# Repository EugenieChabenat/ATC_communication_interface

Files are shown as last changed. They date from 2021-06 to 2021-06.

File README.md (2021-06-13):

# Assistive Technology Challenge: Team Communication
## HackaHealth Geneva 

## Context 
A device  has been developed by this team, to serve as a communication interface for an 8-year-old child that cannot speak but is eager to interact with his environment. 
He needs an efficient tool to communicate and control his tablet (that runs the Grid3 software). 
The goal is to give him more autonomy and a more accurate communication system. 
Our challenges are first of all to create a device easy to use for a child and that does not increase his fatigue. 
We have to consider the low precision of the movements as well as a not very well controlled head hold. 
Our device must meet the criteria of safety, biocompatibility and be easy to use for both the family and the therapists. 
In addition, we aim to produce an object that is easily reproducible, open source and within a reasonable budget. 
This repository contains the codes used for this device, as well as some files for reproducibility of the device itself. 

## File description 
**CAD_files**

- readme_CAD_files

CAD_files/DXF_laser_cutting/ : *CAD files that can be used for laser cutting the pieces of the device*

- readme_DXF_laser_cutting.txt
- cover_window_PMMA_3mm.dxf
- frame_window_PMMA_8mm.dxf
- support_1_CP_aviation_1mm.dxf
- support_2_MDF_4mm.dxf
- support_3_MDF_4mm.dxf

CAD_files/F3D_files/ : *Fusion files of the different pieces for 3d printing*

- readme_F3D_files.txt
- Support_1.f3d
- Support_2.f3d
- Support_3.f3d
- closing_electronic_box.f3d
- cover_window.f3d
- electronic_boc.f3d
- fixation.f3d
- safety_ring.f3d
- tube_cap.f3d
- window_frame_final v4.f3d

CAD_files/STEP_files/ : *Files for 3D printing*

- readme_STEP_files
- Support_1.step
- Support_2.step
- Support_3.step
- closing_electronic_box.step
- cover-window.step
- electronic_box.step
- fixation.step
- frame_window.step
- safety_ring.step
- tube_cap.step

CAD_files/STL_3D_printing/

- readme_STEP_files.txt
- closing_electronic_box_1x.stl
- electronic_box_1x.stl
- fixation_4x.stl
- safety_ring_2x.stl
- tube_cap_4x.stl

**arduino_code**  : *Files to be uploaded on the arduino MCU*

- arduino_code/definitions.h   : *Definition of useful variables*
                                 Important constants:
                                 
  - TIME_FOR_ACTIVATE: Define the time that a sensor is touched before it becomes active [ms]
                                 
  - ADVANCE_TIME: Define the time for which the sensor is activated. (allowed time to scroll) [ms]
                                 
  - TIME_STEP: Define the time spend to navigate between each case in Grid 3 [ms]

- arduino_code/pitches.h	:   *Definition of sound notes for the buzzer*

- arduino_code/prototype_final_V9.ino : *Useful file implementing the module MPR121 and the module LED WS2813*

  - Sensing logic:  
      - *We keep track of the touched values and  taking into consideration a specific priority order we activate a sensor after TIME_FOR_ACTIVATION* 
      - *Activating a sensor means sending a message through Serial communication with the value identifying it and then waiting TIME_STEP to send another identification value until reaching the ADVANCE_TIME*

**python_code**

- python_code/Serial_1.0.exe  : *file to be executed on the terminal when lauching the device connected to the tablet computer*

- python_code/Serial_1.0.py   : *useful functions for controling the device*

**documentation**

-ATC_Team_Communication_User_Manual.pdf :  *pdf file to be carefully read by the users of the manifactured device*

-ATC_Team_Communication_Open_Access_report.pdf : *pdf report to be followed in order to reproduce the project device*

## Requirements 
pip install -r requirements.txt to install all the dependencies

## Launch 
- Launch Grid3 software
- Execute Serial_1.0.exe on the terminal of the computer
- Choose parameters of use via the terminal

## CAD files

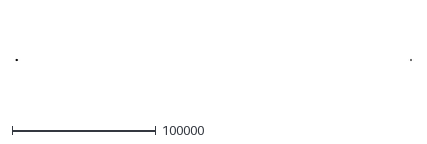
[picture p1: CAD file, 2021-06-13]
CAD_files/DXF_laser_cutting/frame_window_PMMA_8mm.dxf
275014.0 x 600.0

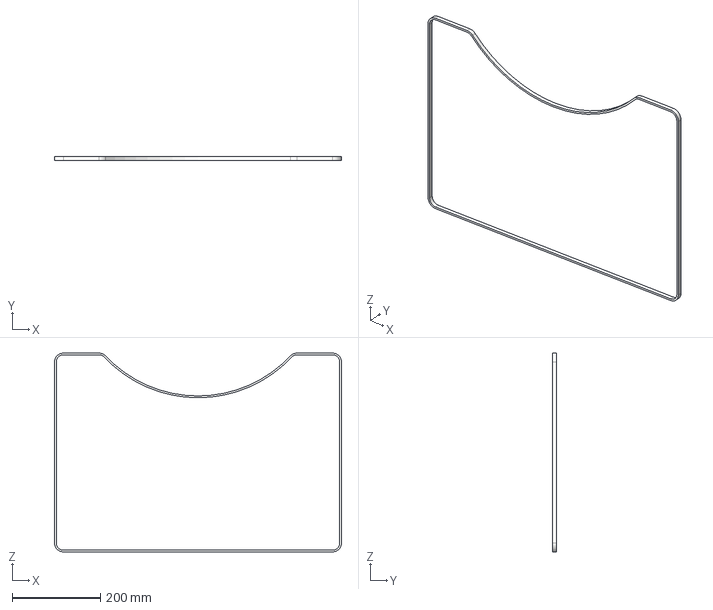
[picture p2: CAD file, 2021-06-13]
CAD_files/STEP_files/frame_window.step
650.0 x 9.00 x 450.0 mm

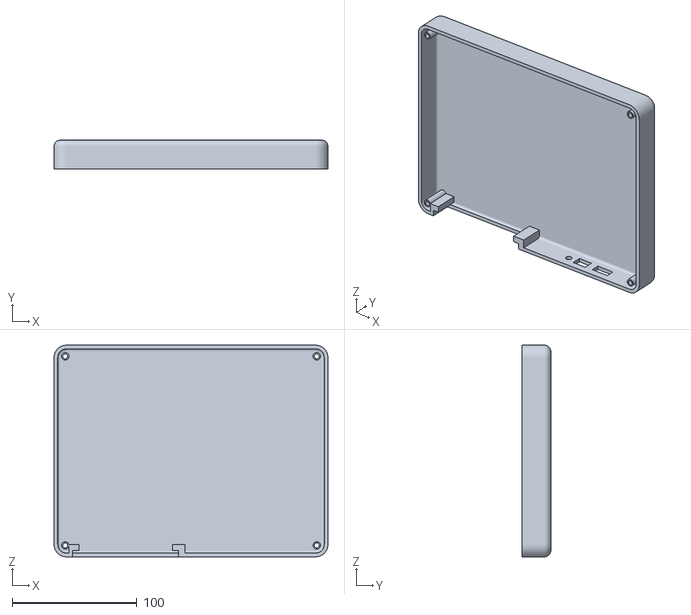
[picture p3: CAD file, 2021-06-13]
CAD_files/STL_3D_printing/electronic_box_1x.stl
220.0 x 23.0 x 170.0

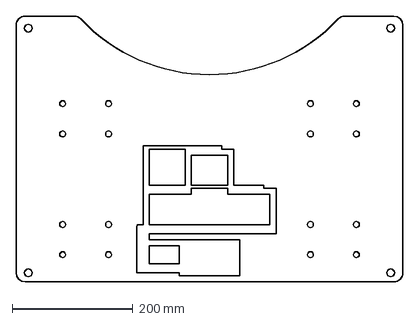
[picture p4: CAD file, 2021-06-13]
CAD_files/DXF_laser_cutting/support_2_MDF_4mm.dxf
640.0 x 440.0 mm

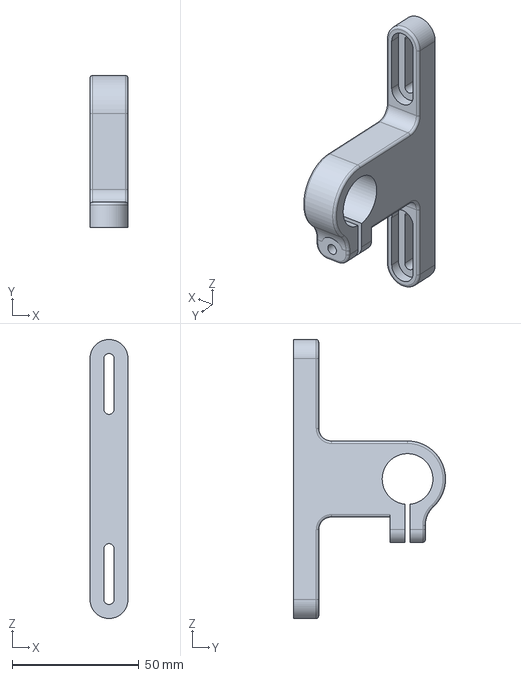
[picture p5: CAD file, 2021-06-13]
CAD_files/STEP_files/fixation.step
15.0 x 60.0 x 110.0 mm

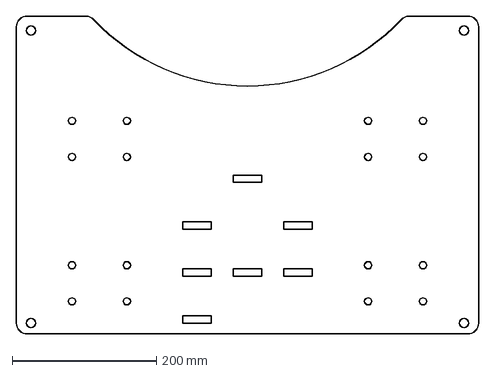
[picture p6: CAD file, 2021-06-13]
CAD_files/DXF_laser_cutting/support_3_MDF_4mm.dxf
640.0 x 440.0 mm

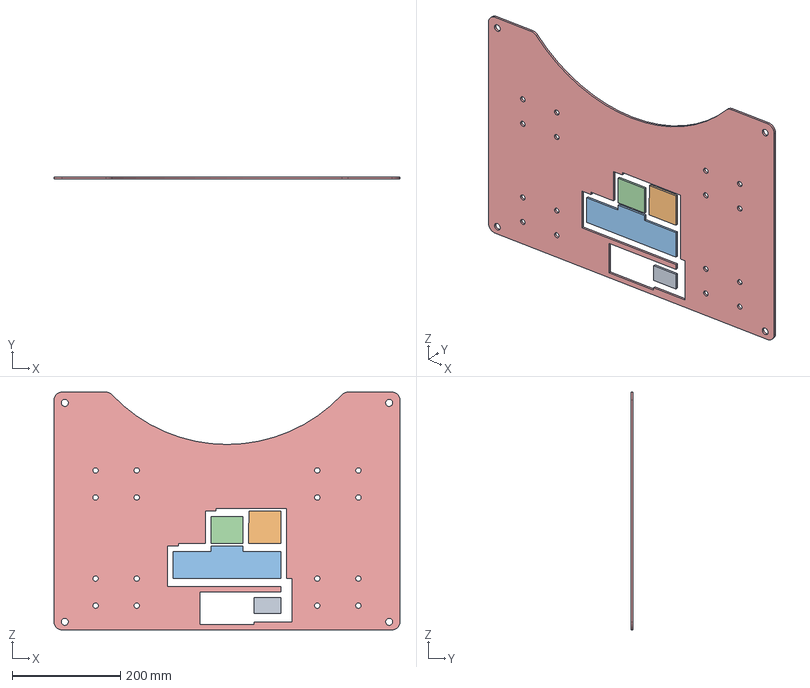
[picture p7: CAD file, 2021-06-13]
CAD_files/STEP_files/Support_2.step
640.0 x 4.00 x 440.0 mm

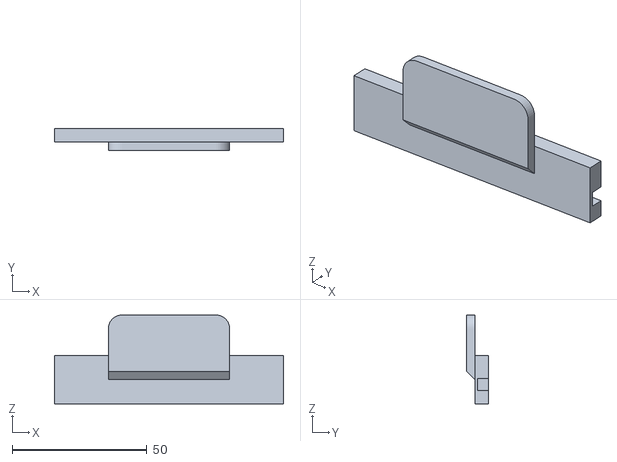
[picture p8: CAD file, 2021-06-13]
CAD_files/STL_3D_printing/closing_electronic_box_1x.stl
85.0 x 8.00 x 33.0

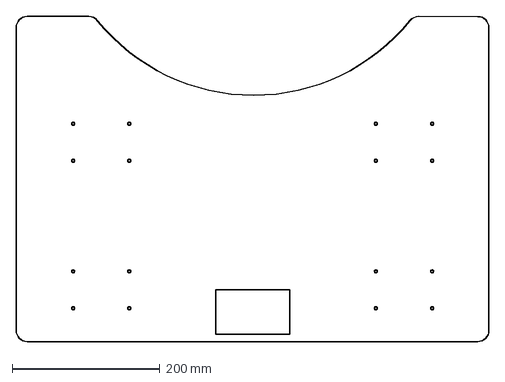
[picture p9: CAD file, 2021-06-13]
CAD_files/DXF_laser_cutting/support_1_CP_aviation_1mm.dxf
640.0 x 440.3 mm

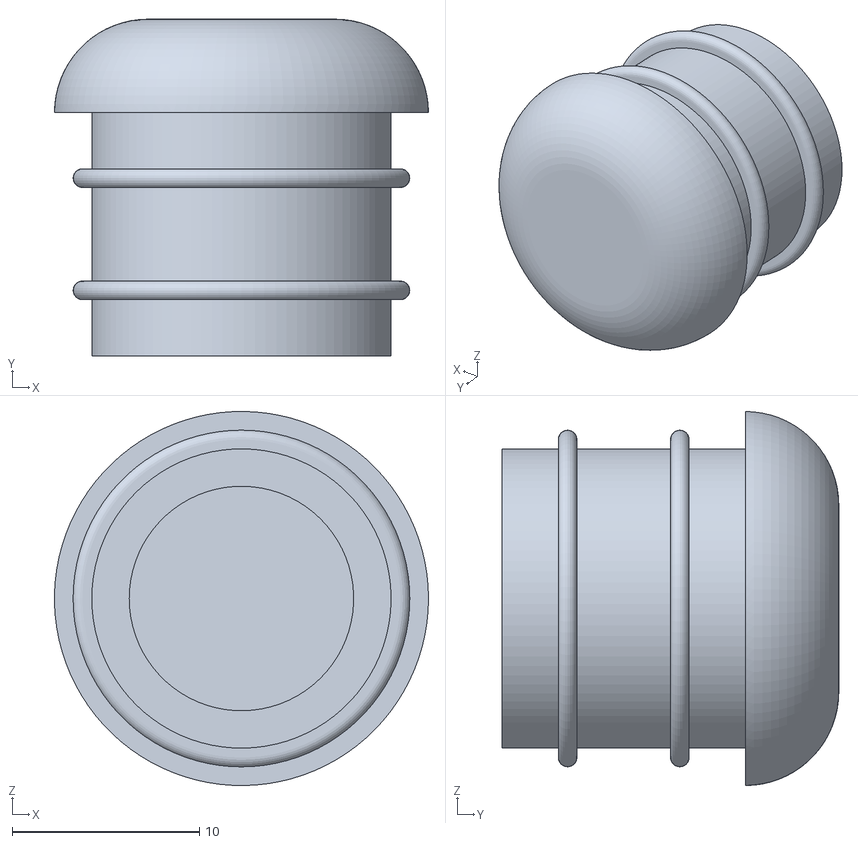
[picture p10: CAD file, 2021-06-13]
CAD_files/STL_3D_printing/tube_cap_4x.stl
20.0 x 18.0 x 20.0

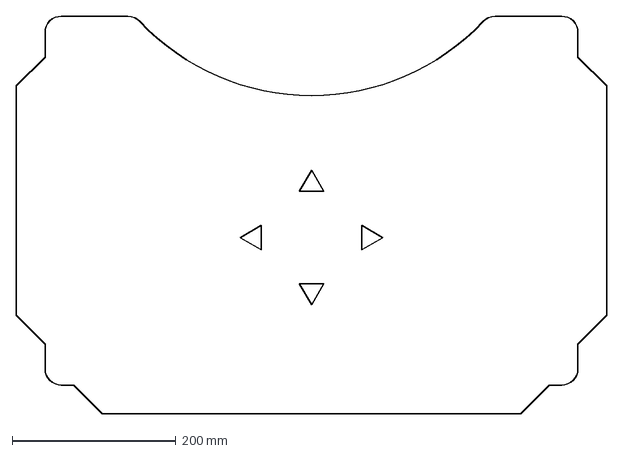
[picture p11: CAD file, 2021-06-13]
CAD_files/DXF_laser_cutting/cover_window_PMMA_3mm.dxf
720.0 x 485.0 mm

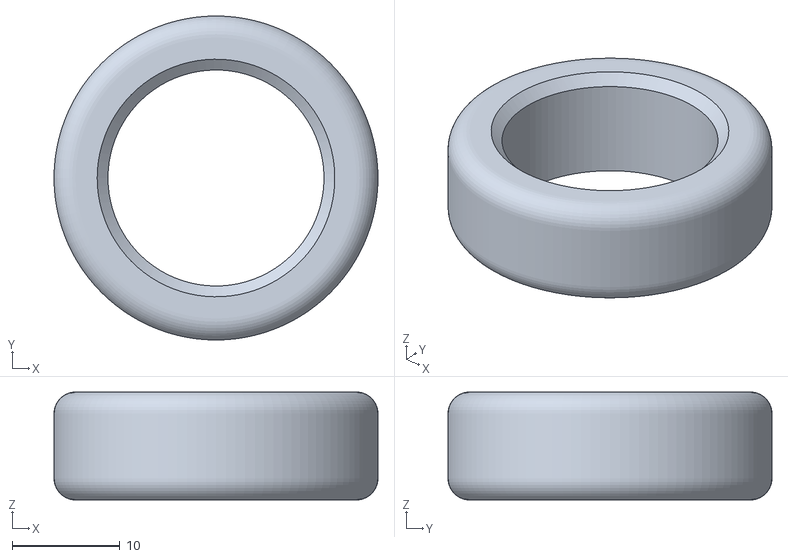
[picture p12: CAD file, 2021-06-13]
CAD_files/STL_3D_printing/safety_ring_2x.stl
30.0 x 30.0 x 10.0

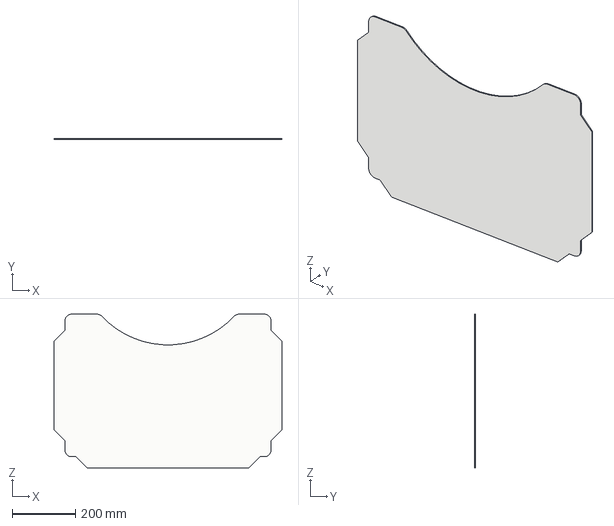
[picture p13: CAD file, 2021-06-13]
CAD_files/STEP_files/cover_window.step
720.0 x 3.00 x 485.0 mm

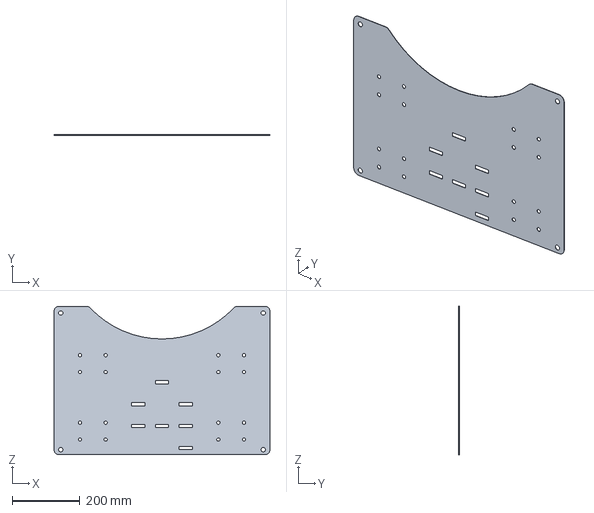
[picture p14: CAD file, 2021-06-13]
CAD_files/STEP_files/Support_3.step
640.0 x 1.00 x 440.0 mm

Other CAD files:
CAD_files/STL_3D_printing/fixation_4x.stl
CAD_files/STEP_files/closing_electronic_box.step
CAD_files/STEP_files/tube_cap.step
CAD_files/STEP_files/electronic_box.step
CAD_files/F3D_files/Support_1.f3d
CAD_files/F3D_files/Support_2.f3d
CAD_files/F3D_files/Support_3.f3d
CAD_files/F3D_files/closing_electronic_box.f3d
CAD_files/F3D_files/cover_window.f3d
CAD_files/F3D_files/electronic_box.f3d
CAD_files/F3D_files/fixation.f3d
CAD_files/F3D_files/safety_ring.f3d
CAD_files/F3D_files/tube_cap.f3d
CAD_files/F3D_files/window_frame_final v4.f3d
CAD_files/STEP_files/Support_1.step
CAD_files/STEP_files/safety_ring.step

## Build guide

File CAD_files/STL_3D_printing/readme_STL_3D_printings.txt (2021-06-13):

This folder contains the pieces that were 3D printed. The pieces are provided in the .stl format which is the format usually used on slicing softwares. It allows to print these parts on any 3d printer. In our case, the pieces were printed on a Prusa MK3S printer using a PETG filament. Each file contains in its name the number of pieces that need to be produced.

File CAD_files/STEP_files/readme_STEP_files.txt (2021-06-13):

This folder contains the 3D pieces to be manufactured in order to reproduce the device. These pieces are provided in a neutral .stp format, which can be opened in any CAD software.

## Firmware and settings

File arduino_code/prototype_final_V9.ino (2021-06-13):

/**************************************
 * Arduino File : ATC project : Team interface communication 
 * Summer Semester 2021 EPFL
 * Authors : Marwen Mokni, Eugénie Chabenat, Jonathan Muheim , Laura puyet
 **************************************/



#include <SoftwareSerial.h>   // Software Serial Port  
#include <Wire.h>
#include "Adafruit_MPR121.h"
#include <FastLED.h>
#include "definitions.h"
#include "pitches.h"

#define buz_pin 3
#define RxD 6                // Pin 4 pour la réception dans l'arduino
#define TxD 7                // Pin 5 pour l'émission de l'arduino
#define led_pin 5

// Initialize the bluetooth Serial 
SoftwareSerial BTSerie(RxD,TxD);  
// Variables
CRGB leds[NB_LEDS];
// You can have up to 4 on one i2c bus but one is enough for testing!
Adafruit_MPR121 cap = Adafruit_MPR121();

uint16_t lp_cnt = 0;
uint16_t baseline[NB_SENSORS]; // we should use structures instead...
bool sensor_touched[NB_SENSORS];// keeps track of the sensors that are currently touched (have boolean value 1, 0 otherwise)
bool sensor_active[NB_SENSORS];// keeps track of the sensor (at most one) that is currently active (have boolean value 1, 0 otherwise)

bool start = false; // linked to starting or turning off the feedback and control 


const byte numChars = 32;
char receivedChars[numChars]; // used to take a specific value from the bluetooth serial communication and set it to the Threshold
bool newData = false;  // will be set to true if there is new given value
char value_change = 'a';  // defining letters to chose which value to change


// Those values can be set by the user using the bluetooth connection  
int threshold_value = 0;
long advance_time = ADVANCE_TIME;
long time_step = TIME_STEP;
long activ_time = TIME_FOR_ACTIVE;


long time_touched[NB_SENSORS];  // the time at which the sensors are touched for last time
long compt_time;
long time_print = 0 ;  // used to control the time of printing and frequency of print 



uint8_t priority[NB_SENSORS] = {0, 3, 5, 2, 1, 4, 6}; // order of priority, order in which we need to check if the sensors are touched
uint8_t threshold_min[NB_SENSORS] = {4,2,3,2,2,1,4};      // define the lower range for each sensor to adjust the sensing, tested across several 
uint8_t threshold_max[NB_SENSORS] = {30,30,30,30,25,33,33};  // Define the upper range of each sensor to avoid miss sensing, tested across several runs


bool buzz = false ; // useful to have a buzzer feedback , calling for attention
//bool first_touched = false; // the first logic was to take the first button touched

uint16_t bl_candidate = 0; // baseline candidate
uint16_t nbrMeasureBaseline = 0; 
uint16_t value = 0; // Insure the selection of the button only once
uint16_t sumBaseline[NB_SENSORS]; 




// Here we declare the melody notes to be played when the buzzer is on : (default melody, should be changed)
int melody[] = {
  NOTE_C7, NOTE_G6, NOTE_G6, NOTE_A6, NOTE_G6, 0, NOTE_B6, NOTE_C7

  
};

int noteDurations[] = {
  4, 8, 8, 4, 4, 4, 4, 4
 
};





/***********************SET UP*************************/
void setup() {
  // put your setup code here, to run once:
  Serial.begin(9600);
  FastLED.addLeds<WS2812, LED_PIN, GRB>(leds, NB_LEDS);
  while (!Serial) { // needed to keep leonardo/micro from starting too fast!
    delay(10);
  }
  Serial.println("Adafruit MPR121 Capacitive Touch sensor test"); 
  
  // Default address is 0x5A, if tied to 3.3V its 0x5B
  // If tied to SDA its 0x5C and if SCL then 0x5D
  if (!cap.begin(0x5A)) {
    Serial.println("MPR121 not found, check wiring?");
    while (1);
  }
  Serial.println("MPR121 found!");
  pinMode(RxD, INPUT);
  pinMode(TxD, OUTPUT);  
  BTSerie.begin(9600);

  
  // We set up to high the led to indicate the arduino is working and the led pin to output
  pinMode(led_pin, OUTPUT);
  digitalWrite(led_pin, HIGH);
  delay(1000);
 
  initialize_baseline();
  initialize_sensor_touched();
  initialize_led();
  cap.setThreshholds(2,1);

  
}


/***********************MAIN LOOP*************************/
void loop() {
  // put your main code here, to run repeatedly:
  // adapt baseline
  // get filtered Data
  // compare filtered Data with Baseline
  // detect which sensor is touched or released
  // switch the LEDs
   
  if(nbrMeasureBaseline == MAX_NBR_MEASURE_BL){
     nbrMeasureBaseline = 0; 
     update_baseline();
      //Serial.print("\t*******BASELINE UPDATED********\n");
        
     }

      bluetooth_change_value(); // This function is used to update some values  to control grid 3 like time for activation etc ...
    
      //debugging_printings();  // this function is very useful to track the different sensors values and give us the raw values
      
      
      // update the touched array: sense which sensors are currently pressed (bool array of length NB_SENSORS)
      // update the time_touched array: contains the time at which the sensors passed from untouched to touched
      update_touched();
  
      // Determine if the On/Off button is activated  
      sense_start();
  
      if(start)
      {
          // update which button is active according to touched_array and the priority (only one active button at a given time)
          // we visit the sensors by order of priority, if it is touched and been touched for more than TIME_FOR_ACTIVE ms then it is active
          update_active();
          // call the function to update the LED status to the active button
          update_led();
          if(buzz)
          {
            tone_time_pressed();
            buzz=false;
          }
      }

      nbrMeasureBaseline++;
      delay(DELAY_MS); 
  
}





/**********************FUNCTIONS**************************/
/* Useful functions in the main loop */
void initialize_sensor_touched(void)
{
  for(uint8_t i = 0; i < NB_SENSORS; i++)
  {
    delay(10);
    sensor_touched[i] = 0;
  }
  
}
void initialize_baseline(void)
{
  for(uint8_t i = 0; i < NB_SENSORS; i++)
  {
    delay(10);
    baseline[i] = cap.baselineData(i);
  }
}





// Define if the board is in its On/Off state : (Feedback from the pictograms and the tablet control)
void sense_start(void)
{
  if( (sensor_touched[FUNCTIONING_BUTTON]) && (millis()-time_touched[FUNCTIONING_BUTTON] >=  activ_time) )
  {


    if(!sensor_active[FUNCTIONING_BUTTON])
    {
      
      start = (!start);
      if(start)
          Serial.println("Setting On the controler");
      else
      {
          Serial.println("Setting Off the controler");
      }
      

    }      
    sensor_active[FUNCTIONING_BUTTON] = true;
    update_led();
  }
  else
  {
      sensor_active[FUNCTIONING_BUTTON] = false;
      update_led();
  }
    


}





// Detect if the buttons are touched and set to one the buttons and their time of activation
void update_touched(void)
{
  int count = 0;
  int thresh =   threshold_value ; // local variable to define the threshold 
  
  for(uint8_t i = 0; i < NB_SENSORS; i++)
  { 
    uint8_t j = priority[i] ; // We also update the touched sensors going in the priority order set as before
    if(!thresh)
        thresh = threshold_min[j];
    if ((cap.filteredData(j) + thresh  <= baseline[j])  && (cap.filteredData(j) + threshold_max[j] >= baseline[j]) ) // sensor is currently pressed when it's in the range of sensing
    {
      if(!sensor_touched[j]) // if was not touched before, we record the time
      {
        time_touched[j] = millis();
        
        
      }
      
        sensor_touched[j] = true;

      // if inthe priority table one sensor is set to touched we have to initialize also the time of the other sensors  
      for(uint8_t k = i+1; k < NB_SENSORS; k++ )
        {
          // if the button is not active we  set his timing to zero to avoid his activation before the needed button
          if (sensor_touched[priority[k]])
          {
                time_touched[priority[k]] = millis();
          }
        }
        return;

        
    }
    else
    {
      sensor_touched[j] = false;// check whether we need to have a hysteresis (if glitching happen)
    }
  }
}





// This function insures that only one button is activated 
void update_active(void)
{
  for(uint8_t i = 1; i < NB_SENSORS; i++)
  { 
    
    // if the sensor in i-th level of priority is touched AND has been touched for more than TIME_FOR_ACTIVE [ms], then it is activated
    if( (sensor_touched[priority[i]]) && (millis()-time_touched[priority[i]] >= activ_time) )
    {
      // if it is the buzzer that has just been activated (the buzzer will be activated AND wasn't yet) then we have to play a tone
      if((priority[i] == BUZZER_BUTTON) && (!sensor_active[BUZZER_BUTTON]))
      {
        buzz = true;
      }
      

      // Activate only once the printed message at each time we have an activated sensor
      if(!sensor_active[priority[i]] && (millis()-time_touched[priority[i]] <= advance_time))
      {
              BTSerie.println(priority[i]);
              Serial.println(priority[i]);  // Backup  for the bluetooth module  
              compt_time = millis();
      }

      
      // This logic will permit to sweep the digital pictograms on the tablet grid
      if(sensor_active[priority[i]] && millis() - compt_time > time_step &&  (priority[i] != VALIDATE_BUTTON) &&  (priority[i] != BUZZER_BUTTON) )
      {
              BTSerie.println(priority[i]);
              Serial.println(priority[i]);  //Backup for the bluetooth module 
              compt_time = millis();
      }

      
      // This condition is needed to insure that after the sweeping time the sensor stays inactive 
      if(millis()-time_touched[priority[i]] > advance_time)
            sensor_active[priority[i]] = false;
      else
            sensor_active[priority[i]] = true;
      
      
      // set all other sensor_active to false and leave the function
      for(uint8_t j = i+1; j < NB_SENSORS; j++ )
      {
        // if it is the buzzer that has just been desactivated (the buzzer was activated) (AND isn't now) then we have to stop playing the tone
        sensor_active[priority[j]] = false;
        // if the button is not active we can also set his timing to zero
        time_touched[priority[j]] = millis();
      }
      return;
    }
    else
    {
      // Set every state of sensors not touched to zero 
      sensor_active[priority[i]] = false;
      
    }
  }
  
}




// This function set the leds to an intial state
void initialize_led(void)
{
  for (uint8_t i = 0; i < NB_LEDS; i++)
  {
    leds[i] = CRGB::Black;//(255,125,0);// LEDs initialized to Black
  }
  FastLED.show();// apply to the LED strip
}


// Depending on the touched sensor it will trun it On
void update_led(void)
{
  led_states state_led_i;// see in the definition section what values can state_led_i take (OFF, WHITE, RED, GREEN, BLUE...)
  for (uint8_t i = 0; i < NB_SENSORS; i++) //update the state of the i-th led
  {
    state_led_i = OFF;
    if(sensor_active[i] == true)
    {
      state_led_i = WHITE;
      // set the led lights green when we open the device 
      if( i == FUNCTIONING_BUTTON && start)
               state_led_i = GREEN;
      else if(i == FUNCTIONING_BUTTON && (!start))
               state_led_i = RED;
           
      
    }
     write_led(i, state_led_i);// this function is need because of each sensors has not the same number of LEDs (prototyping hazard :( )
  }
  //delay(100);
  //FastLED.show();// apply to the LED strip
}





void write_led(uint8_t index_sensor, led_states state)
{
  CRGB colour;
  uint8_t offset = 0;
  switch(state)
  {
    case OFF:  colour = CRGB::Black;//CRGB colour(0,0,0);// colour = (0,0,0);
    
      break; 
    case WHITE: colour = CRGB::White;//CRGB colour(255,255,255);// colour = (255,255,255);
      //Serial.println("WHITE"); 
      break; 
    case RED:   colour = CRGB::Red;//CRGB colour(255,0,0);// colour = (255,0,0);
      break; 
    case GREEN: colour = CRGB::Green;//CRGB colour(0,255,0);// colour = (0,255,0);
      break; 
    case BLUE:  colour = CRGB::Blue;//CRGB colour(0,0,255);// colour = (0,0,255);
      break; 
  }
  switch(index_sensor)
  {
    case 0: offset = 0;
      break; 
    case 1: offset = 3;
          break; 
    case 2: offset = 6;
          break; 
    case 3: offset = 9;
          break; 
    case 4: offset = 18;      
          break; 
    case 5: offset = 12;
          break; 
    case 6: offset = 15;
          break; 
    case 7: offset = 21;
          break; 
    case 8: offset = 21;
          break; 
    case 9 : offset = 21;
          break; 
  }
  leds[offset] = colour;
  leds[offset + 1] = colour;
  leds[offset + 2] =  colour; 
  FastLED.show();// apply to the LED strip

}


void update_baseline(void)
{
  for(uint8_t i = 0; i < NB_SENSORS; i++)
  {
    // the baseline is updated only if the current baselinData (baseline_candidate) is larger than the one recorded 
    // this avoids a problem if the user has his hand on a sensor when resetting the µcontroller
     bl_candidate = cap.baselineData(i);
     if (baseline[i] < bl_candidate)
     {
        baseline[i] = bl_candidate;
     }
     
  }
}

void print_led_colour(void)
{
    Serial.print("\n Colour:");
  for (uint8_t i = 0; i < NB_LEDS; i++)
  {
    Serial.print("\t"); Serial.print(leds[i][12]);
  }
  
}


void debugging_printings(void)
{
  Serial.print("\n\t\tlp_count: ");Serial.print(lp_cnt);
  Serial.print("\n nb:\t");
  for (uint8_t i = 0; i < NB_SENSORS; i++)
  {
    Serial.print("\t"); Serial.print(i);
  }
  Serial.print("\n Touched:");
  for (uint8_t i = 0; i < NB_SENSORS; i++)
  {
    Serial.print("\t"); Serial.print(sensor_touched[i]);
  }
  Serial.print("\n Baseline:");
  for (uint8_t i = 0; i < NB_SENSORS; i++)
  {
    Serial.print("\t"); Serial.print(baseline[i]);
  }
  Serial.print("\n Filtered:");
  for (uint8_t i = 0; i < NB_SENSORS; i++)
  {
    Serial.print("\t"); Serial.print(cap.filteredData(i));
  }
  Serial.print("\n");

  delay(200);
}

void send_funct(void){
  Serial.print("Filt: ");
  for (uint8_t i=0; i<12; i++) {
    Serial.print(cap.filteredData(i)); Serial.print(",");
  }
  Serial.println();
  Serial.print("Base mean: ");
  for (uint8_t i=0; i<12; i++) {
    Serial.print( baseline[i]); Serial.print(",");
  }
    Serial.println();

 Serial.println();
  Serial.print("Base true: ");
  for (uint8_t i=0; i<12; i++) {
    Serial.print(cap.baselineData(i)); Serial.print(",");
  }
    Serial.println();

  delay(500);
}





// This function will be useful to use the python executable as a place where you can change the different numbers

void bluetooth_change_value(void)
{
  
  bool bt_start = false;
  char rc ; 
  if(BTSerie.available())
  {
     rc = BTSerie.read();
     if(rc == '1')
        bt_start = true;
     else
        bt_start = false;
  }
  while(bt_start)
  {
  recvWithEndMarker();
  bt_start = set_threshold_value();
  delay(50);
  if(!bt_start)
        Serial.println("Finished setting the values");
  }
}



// The function is inspired from a forum given the method to read numbers using Serial communication
void recvWithEndMarker(void) {
    static byte ndx = 0;
    char endMarker = 'f';
    char rc;
    
      if(BTSerie.available() > 0  && newData == false) {
        rc = BTSerie.read();
        if (rc != endMarker) {
            receivedChars[ndx] = rc;
            ndx++;
            if (ndx >= numChars) {
                ndx = numChars - 1;
            }
        }
        else {
            value_change = receivedChars[ndx-1] ; // Will define which value to change 
            receivedChars[ndx-1] ='\0' ;  // reset the last string value to terminates it
            ndx = 0;
            newData = true;
        }
    }
}

// We will try to change the parameter values 
bool set_threshold_value(void)
{
  if(newData == true)
  {

      switch(value_change)
    {
      case 'a':
              threshold_value = atoi(receivedChars);
              Serial.print("The new value of threshold is ...");
              Serial.println(threshold_value);
              BTSerie.print("The threshold is set to the value ...");
              BTSerie.println(threshold_value);
              break; 
      case 'b': 
              advance_time = atol(receivedChars);
              Serial.print("The new value of sweeping time is ...");
              Serial.println(advance_time);  
              BTSerie.print("The time to sweep is set to the value...");
              BTSerie.println(advance_time);
              break; 
      case 'c': 
              time_step = atol(receivedChars);
              Serial.print("The new value of step advance is ...");
              Serial.println(time_step);  
              BTSerie.print("The step advance time is set to the value ...");
              BTSerie.println(time_step);
              break; 
      case 'd':
              activ_time = atol(receivedChars);
              Serial.print("The new value of activation time is ...");
              Serial.println(activ_time);  
              BTSerie.print("The activation time is set to  the value ...");
              BTSerie.println(activ_time);
              return false;
              break;
  
    }
    newData = false;
  }
  return true;
  
}



// This function is useful to generate a sound using the piezo buzzer

void tone_time_pressed(){

  for (int thisNote = 0; thisNote < (sizeof(noteDurations) / sizeof(int)); thisNote++) {

    // to calculate the note duration, take one second divided by the note type.
    //e.g. quarter note = 1000 / 4, eighth note = 1000/8, etc.
    int noteDuration = 1000 / noteDurations[thisNote];
    tone(buz_pin, melody[thisNote], noteDuration);
    // to distinguish the notes, set a minimum time between them.
    // the note's duration + 30% seems to work well:
    int pauseBetweenNotes = noteDuration * 1.30;
    delay(pauseBetweenNotes);
    // stop the tone playing:
    noTone(buz_pin);
  }
                                    
  }

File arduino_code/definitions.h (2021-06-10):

// Define constants
#define LED_PIN       13
#define NB_LEDS      24
#define NB_SENSORS    7
#define MAX_NBR_MEASURE_BL 100
#define THRESHOLD     3 // difference between the filtered data and baseline above which the sensors is considered as touched
#define BL_UPDT_RATE  5 // Baseline update rate (how many loops before we update the baselines)
#define DELAY_MS   20 // delay to be waited between the main loops in [ms]
#define TIME_FOR_ACTIVE  1000 // time a button must be pressed before it becomes active in [ms]
#define TIME_STEP 750
#define ADVANCE_TIME 5000  // The time allowed to advance on the grid 
#define BUZZER_BUTTON 3 // the ide of the button corresponding to asking for attention (SOS)
#define BOTTOM_BUTTON 5
#define VALIDATE_BUTTON 1
#define FUNCTIONING_BUTTON 0
// the LED states (OFF, WHITE, RED, BLUE or GREEN) we could define other mixed colors too
enum led_states{OFF, WHITE, RED, GREEN, BLUE};

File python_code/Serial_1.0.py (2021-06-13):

"""
Created for the ATC project: Project communication interface

@author: Marwen Mokni
"""

import serial
import serial.tools.list_ports
import numpy as np
import warnings
import pyautogui

import time



# This function is useful to write back to the arduino and verify if the value was set in the arduino
def write_data(x, index):

    value = "{}{}f".format(int(x),index) # we attach here the value of the advance time with 'a' the index coresponding 
    print(value)                                 # in the arduino code
    ser.write(bytes(value, 'utf-8'))  # here we will send the message to the arduino 
    #time.sleep(0.7)
    #if(ser.in_waiting):
    ser_bytes = ser.readline()[:-2].decode("utf-8")
    print(ser_bytes)



# Connect to the serial COM port
def connect_to_arduino_if_exist():
    print("Connection to Arduino")
    arduino_ports = [
        p.device
        for p in serial.tools.list_ports.comports()
        if 'Arduino' in p.description  # May need adjustments to match other devices
    ]
    try:
        if not arduino_ports:
            raise IOError("No Arduino found")
        if len(arduino_ports) > 1:
            warnings.warn('Multiple Arduinos found - using the first')
        ser = serial.Serial(port =arduino_ports[0], baudrate ="9600");
        #print("Arduino is connected")
    except:
        #print("Arduino is not connected")
        ser = []
    return ser

def key(i):
        switcher={              # Need to be adapted to the differentkeys chosen to be set
                0:'q',
                1:'return',
                2:'up',
                3:'w',
                4:'left',
                5:'right',
                6:'down',
                7:'x',
                8:'q'
             }
        return switcher.get(i,"Invalid key")


    
    
    
ser = connect_to_arduino_if_exist()
if ser == []:
    print("Using the bluetooth connection")
    ser = serial.Serial('COM8', 9600) # The communication ports is to be defined 
    

## This part will be useful to adapt the different values of our arduino:
set_values = input("Do you want to change the parameters: ") # Taking input from user
ser.write(bytes(set_values, 'utf-8'))
if(set_values == '1'):
    advance_time = input("Insert the advance time: ")
    write_data(advance_time, 'b')            # This part is used to adjust the time advance                                
    time_step = input("Insert the speed of each step: ")
    write_data(time_step,'c')                # Same for sweeping the grid 3
    activ_time = input("Set the time before each activation: ")
    write_data(activ_time, 'd')        #  we also adjust the time before activating each sensor

    # Adapting the threshold can be optional if we have higher sensitivity of the capacitive sensors
    """
    threshold = input("Insert the threshold for the sensors: ")
    write_data(threshold, 'a')
    """
else:
    print("The arduino is working with the initial set values")





    
# Main loop of the python file that sense the values given by the arduino
while True:
    # Ce code fonctionne pour voir la valuer du bouton touched et released 
    ser_bytes = ser.readline().decode('ascii')


    a = int(ser_bytes)
    print("The pushed button is {} corresponding to the key: {}  ".format(a, key(a) ))
    
    # upper button is referring to 2
    # right button is referring to 5
    # down button is referring to 6
    # Left button is referring to 4
    # the return button is referring to 0
    
    # using a qwertz keyboard 
    if a != 0 :
         pyautogui.press(key(a))

    

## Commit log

2021-06-13 CAD files
    [Support_1.f3d, Support_1.step, Support_2.f3d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]
2021-06-13 Arduino file using capacitive sensors
